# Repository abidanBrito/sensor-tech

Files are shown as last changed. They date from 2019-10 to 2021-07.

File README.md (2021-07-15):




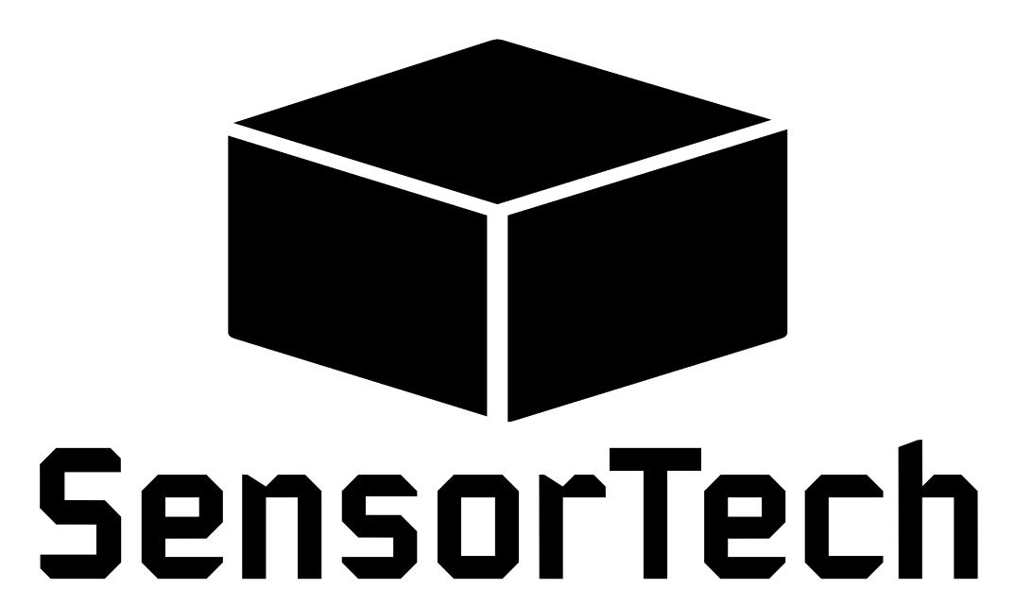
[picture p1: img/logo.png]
Project_Logo


Electronic prototype to **monitor several environmental magnitudes** through self-implemented sensors. Field data collection at your fingertips!

## TABLE OF CONTENTS
1.  [Motivation](#motivation)
2.  [Technologies and Frameworks](#technologies-and-frameworks)
3.  [System Design](#system-design)
4.  [Functionalities and Features](#functionalities-and-features)
5.  [Documentation](#documentation)
6.  [Acknowledgements](#acknowledgements)

## MOTIVATION
This project is a team effort for our first semester class CDIO. It aims to **optimize all agricultural activity**, providing meaningful realtime data.

## TECHNOLOGIES AND FRAMEWORKS
### Electronic Devices and Components
*   Sparkfun **ESP8266 Thing Dev** Board.
*   Adafruit **ADS1115** 16-bit ADC.
*   DFROBOT **SEN0193** Soil Moisture Sensor.
*   Lantronix **A2235-H** GPS Receiver.
*   InvenSense **MPU-9250** Accelerometer.
*   Adafruit **BMP280** Barometric Pressure & Altitude Sensor.
*   **HC-SR04** Ultrasonic Distance Sensor. 
*   Operational amplifier.
*   Photodiode.
*   AND logic gate.
*   NTC thermistor.
*   Resistors.

### REST APIs
*   ThingSpeak - IoT Analytics and integration with MATLAB.
*   Dweet - Simple messaging and alerts. 

### Software Development 
*   Arduino IDE. 
*   Third-party text editors.

## SYSTEM DESIGN
### Sofware Architecture
Check the [documentation](Technical_Documentation.pdf) (spanish) for a detailed breakdown of both the overall design and the dependencies it relies on.

### Hardware Architecture
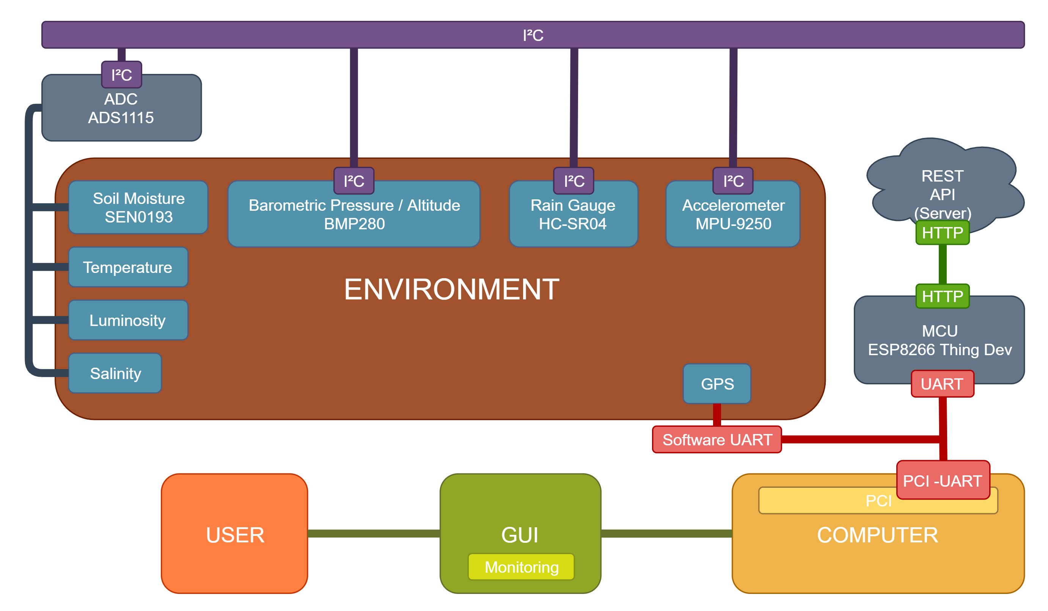
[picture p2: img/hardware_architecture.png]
Hardware Architecture Diagram

Refer to the [documentation](Technical_Documentation.pdf) (spanish) for further details and schematics.

## FUNCTIONALITIES AND FEATURES 
*   \[x] Salinity sensor (electrical conductivity).
*   \[x] Soil Moisture sensor.
*   \[x] Temperature sensor.
*   \[x] Luminosity sensor.
*   \[x] Barometric pressure and altitute sensor.
*   \[x] Anti-theft system (Wake on Motion).
*   \[x] Hibernation mode (Deep Sleep).
*   \[x] Rain Gauge (experimental).
*   \[x] GPS receiver.
*   \[x] REST server.
*   \[x] PCB Design.

## DOCUMENTATION
Please, refer to the [technical documentation](Technical_Documentation.pdf) (spanish) if you have any doubts about the system. It can be found in the form of a PDF file, which goes over everything you need to get you up and running, from schematics and pins to dependencies and sensor calibration.

## ACKNOWLEDGEMENTS
I would like to express my sincere gratitude to my teacher **Mª Asunción Pérez Pascual** for her invaluable support, feedback and encouragement throughout the development of this project, and to **Universitat Politècnica de València** for providing us with both the knowledge and the tools needed to complete it.

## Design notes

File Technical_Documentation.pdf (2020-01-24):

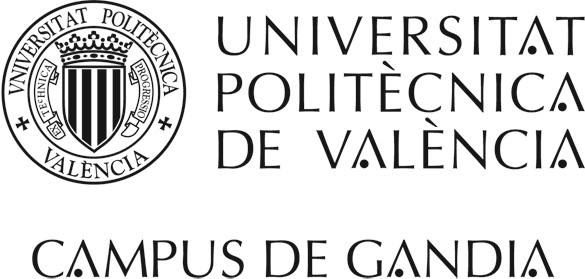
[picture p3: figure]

1

## Proyecto GTI_1A (GTI_1A_19_TEAM_02)

## Sonda agrícola e-Horta

## Documento Técnico de Diseño

Volumen 1

Documento Técnico de Diseño | Pág.2
GTI 1A 19 TEAM 02
Vol. 1
ÍNDICE
PROPÓSITO | 6
ALCANCE | 6
DEFINICIONES, ACRÓNIMOS Y ABREVIATURAS | 6
ESTRUCTURA DEL DOCUMENTO | 7
CARACTERÍSTICAS DEL SISTEMA | 7
Tabla 1. Funcionalidades | 8
ARQUITECTURA HARDWARE DEL SISTEMA | 8
Diagrama de bloques | 8
Ilustración 1. Diagrama de bloques | 8
Esquemático del circuito | 8
Ilustración 2. Esquemático del circuito | 8
PCB implementado | 9
Ilustración 3. Diseño de la PCB | 9
MEDIDA HUMEDAD | 9
Descripción | 9
Ilustración 4. Esquemático del sensor de humedad | 10
Calibración | 10
Testeo | 10
Tabla 2. Valores de humedad | 11
MEDIDA SALINIDAD | 11
Descripción | 11
Ilustración 5. Esquemático del sensor de salinidad | 11
Calibración | 11
Gráfica 1. Valores del sensor de salinidad | 11
Testeo | 11
Gráfica 2. Valores de Salinidad | 12
MEDIDA TEMPERATURA | 12
Descripción | 12
Ilustración 6. Esquemático del sensor de temperatura | 13
Calibración | 13
Testeo | 13
Gráfica 3. Valores del sensor de temperatura | 13

Vol. 1

PRESIÓN BAROMÉTRICA Y ALTITUD | 13
Descripción | 13
Ilustración 7. Esquemático del sensor de presión barométrica | 14
Calibración | 14
Testeo | 14
LUZ AMBIENTE | 14
Descripción | 14
Ilustración 8. Esquemático del sensor de luminosidad | 15
Calibración | 15
Tabla 3. Valores del sensor de luminosidad | 15
Testeo | 15
PLUVIÓMETRO | 15
Descripción | 15
Ilustración 9. Esquemático del pluviómetro | 15
Calibración | 15
Testeo | 15
LOCALIZACIÓN | 16
Descripción | 16
Ilustración 10. Esquemático del GPS | 16
Calibración | 16
Testeo | 16
RED DE NODOS | 16
Ilustración 11. Red de nodos | 17
SOFTWARE | 17
CLASES | 17
Ilustración 12. Diagrama de la clase del sensor BMP280 | 17
Ilustración 13. Diagrama de la clase del sensor SEN0193 | 18
Ilustración 14. Diagrama de la clase del sensor de luminosidad | 18
Ilustración 15. Diagrama de la clase del sensor de temperatura | 18
Ilustración 16. Diagrama de la clase del pluviómetro | 19
Ilustración 17. Diagrama de la clase del sensor de salinidad | 19
LIBRERÍAS | 19
PROGRAMA | 19
Ilustración 18. Diagrama de la configuración del programa | 20

Vol. 1
Figuras
Ilustración 1. Diagrama de bloques | 8
Ilustración 2. Esquemático del circuito | 8
Ilustración 3. Diseño de la PCB | 9
Ilustración 4. Esquemático del sensor de humedad | 9
Ilustración 5. Esquemático del sensor de salinidad | 10
Ilustración 6. Esquemático del sensor de temperatura | 11
Ilustración 7. Esquemático del sensor de presión barométrica | 12
Ilustración 8. Esquemático del sensor de luminosidad | 13
Ilustración 9. Esquemático del pluviómetro | 14
Ilustración 10. Esquemático del GPS | 15
Ilustración 11. Red de nodos | 15
Ilustración 12. Diagrama de la clase del sensor BMP280 | 16
Ilustración 13. Diagrama de la clase del sensor SEN0193 | 16
Ilustración 14. Diagrama de la clase del sensor de luminosidad | 17
Ilustración 15. Diagrama de la clase del sensor de temperatura | 17
Ilustración 16. Diagrama de la clase del pluviómetro | 17
Ilustración 17 Diagrama de la clase del sensor de salinidad | 18
Ilustración 18. Diagrama del programa completo | 18

Vol. 1
TABLAS Y GRÁFICAS
Tabla 1. Funcionalidades | 7
Tabla 2. Valores de humedad | 10
Gráfica 1. Valores del sensor de salinidad | 11
Tabla 3. Valores del sensor de luminosidad | 13
Gráfica 3. Valores del sensor de temperatura | 13

Vol. 1

### 1 INTRODUCCIÓN

E-Horta es una sonda agrícola capaz de realizar lecturas de diversas magnitudes físicas. Recopila información de campo sensible, a fin de monitorizar y optimizar la actividad agrícola.
Este prototipo electrónico recoge datos de la humedad de la tierra, la salinidad y temperatura del agua de riego, la temperatura ambiente, la presión barométrica, la altitud del terreno, la intensidad lumínica, el volumen de precipitaciones y la geolocalización del dispositivo. Además, incorpora un pequeño sistema antirrobo y otro de autoabastecimiento (célula fotovoltaica y batería).
Para minimizar el consumo energético, la sonda realiza mediciones cada cierto tiempo (configurable). Inmediatamente entra en modo de hibernación o stand-by, hasta la siguiente captura de datos o la interrupción física (vibraciones).
Para implementar las susodichas funcionalidades, se ha optado por utilizar el microcontrolador SparkFun ESP8266 Thing Dev, el convertidor analógico-digital Adafruit ADS1115 16-bit, sensores varios (tanto analógicos como digitales) y múltiples componentes electrónicos. Este microcontrolador tiene la ventaja de utilizar la plataforma de desarrollo Arduino, y está programado en lenguaje C++.

### 1.1 PROPÓSITO

En este documento se especifican las características técnicas del producto, así como su funcionamiento. Además, proporciona información sobre los sensores utilizados.
Éste es un documento técnico dirigido a un público con conocimiento tecnológico mínimo, relativo al campo de la electrónica y la programación.
Su redacción pretende exponer de manera rigurosa y objetiva las capacidades, propiedades y limitaciones de e-Horta. Con ello, se espera concretar las amplias posibilidades del producto.

### 1.2 ALCANCE

Este prototipo tiene como finalidad que el cliente sepa en todo momento la situación de su campo, sin necesidad de ir a éste todos los días, y poder saber cuándo tiene que regar más, o cuándo el agua tiene demasiada sal y puede estropear los cultivos.
El sistema es capaz de mostrar los niveles de humedad, salinidad, temperatura en agua, temperatura ambiente, presión barométrica, altitud, luminosidad y precipitaciones. También está equipado con un sistema de posicionamiento global. El dispositivo se encuentra aislado en una caja estanca; se puede estropear si alguno de sus componentes internos entra en contacto con el agua, provocando un cortocircuito.

Vol. 1

### 1.3 DEFINICIONES, ACRÓNIMOS Y ABREVIATURAS

ADC: Convertidor analógico-digital (Analog-to-Digital Converter).
GPS: sistema de posicionamiento global (Global Positioning System).
PCB: placa de circuito impreso (Printed Circuit Board); superficie constituida por buses de un material conductor, laminadas sobre una base no conductora.
API: interfaz de programación de aplicaciones (Application Programming Interface). REST: transferencia de estado representacional (Representational State Transfer); estilo de arquitectura software para sistemas hipermedia distribuidos.
CEI: Comisión Electrotécnica Internacional.
RAEE: Residuos de Aparatos Eléctricos y Electrónicos.
IDE: entorno de desarrollo integrado (Integrated Development Environment). TCP: Transmission Control Protocol.
IP: Internet Protocol address.
HTTP: Hypertext Transfer Protocol.
UART: Universal Asynchronous Receiver-Transmitter. I2C: Inter-Integrated Circuit.
WOM: Wake on Motion.
NMEA: National Marine Electronics Association.
deepSleep: función del microcontrolador que le permite activar el modo Stand-by. BMP280: sensor digital de presión barométrica absoluta, altitud y temperatura ambiente.
MPU9250: acelerómetro utilizado para el sistema antirrobo.
A2235-H: recibidor de GPS utilizado.
SEN0193: sensor de humedad del suelo utilizado.
Buck-boost: convertidor DC-DC con un voltaje de salida mayor o menor que el voltaje de entrada.
Célula fotovoltaica / fotocélula: dispositivo electrónico que permite transformar la energía lumínica en energía eléctrica mediante el efecto fotoeléctrico, generando energía solar fotovoltaica.

Vol. 1

### 1.4 ESTRUCTURA DEL DOCUMENTO

El documento sigue la siguiente estructuración lógica de los contenidos:
1) Introducción concisa, descripción detallada del proyecto y documentos referenciados.
2) Visión general del sistema.
3) Funcionalidades, calibraciones y testeos del prototipo.
4) Mapa de red de nodos.
5) Software implementado y dependencias (librerías).
6) Conclusiones del trabajo realizado y posibles líneas de mejora.
7) Referencias del documento.

### 2 SISTEMA

El funcionamiento del sistema se basa en la transferencia de datos extraídos / capturados por los sensores al microcontrolador. Posteriormente, son enviados a un servidor web (API REST), que los muestra al usuario final en forma de gráficos. Finalmente, el microcontrolador entra en modo hibernación (deepSleep), “se duerme”, para ahorrar energía. No obstante, si alguien intentase robarlo, éste se despertaría ipso facto y notificaría la incidencia.

### 2.1 CARACTERÍSTICAS DEL SISTEMA

El sistema se alimenta a través de una pequeña célula fotoeléctrica, acoplada a un convertidor buck-boost y una batería de litio. El convertidor buck-boost se utiliza para garantizar un nivel de voltaje de salida estable.
Para maximizar la eficiencia energética utilizamos el modo deepSleep y una PCB. Esta última además de mejorar el diseño, mantenimiento y apariencia, también evita cambios bruscos de impedancia y reflexiones en altas frecuencias.
Como medida de protección, se ha optado por aislar toda la circuitería en una caja estanca, cuyo grado de protección es IP55, de acuerdo con la regulación de la norma CEI 60529. Es decir, protección contra polvo y frente a chorros de agua. Como medida de seguridad, se ha implementado un rudimentario sistema antirrobo, utilizando el acelerómetro para detectar vibraciones o movimientos, compartiendo el bus de interrupción con la interrupción del modo deepSleep.
La directiva 2011/65/UE es aplicable. El producto también cumple la normativa europea de concentración máxima de sustancias peligrosas. El reciclaje de aparatos eléctricos y electrónicos es una cuestión sensible. Éstos están formados por diferentes materias peligrosas. La negligencia de su correcto tratamiento o reciclaje puede suponer contaminación ambiental. Siguiendo el Real Decreto 110/2015, se insta a extraer los componentes internos de la caja y llevarlos al punto limpio más cercano; depositando la caja y los residuos electrónicos por separado y en sus respectivas localizaciones. El reciclaje de los RAEE depende del papel activo de

Vol. 1

cada uno de nosotros. Debemos concienciarnos y entender la responsabilidad y deuda ecológica que ello conlleva.
Los siguientes sensores cumplen la normativa RoHS: MPU-9250, BMP280, A2235-H.
Parámetro | Mín. | Máx. | Unidades
Humedad | Seco | Sumergido | %
Salinidad | Agua destilada | Cortocircuito | %
Temperatura | 0 | 40 | ºC
Presión | 300 | 1100 | hPa
Luz | Oscuridad (0) | Soleado (3.7) | mV
Pluviómetro | 0 | 0.45 | l
Altitud | -150 | 9140 | m
Tabla 1. Funcionalidades con sus rangos de medida

### 2.2 ARQUITECTURA HARDWARE DEL SISTEMA

### 2.2.1 Diagrama de bloques

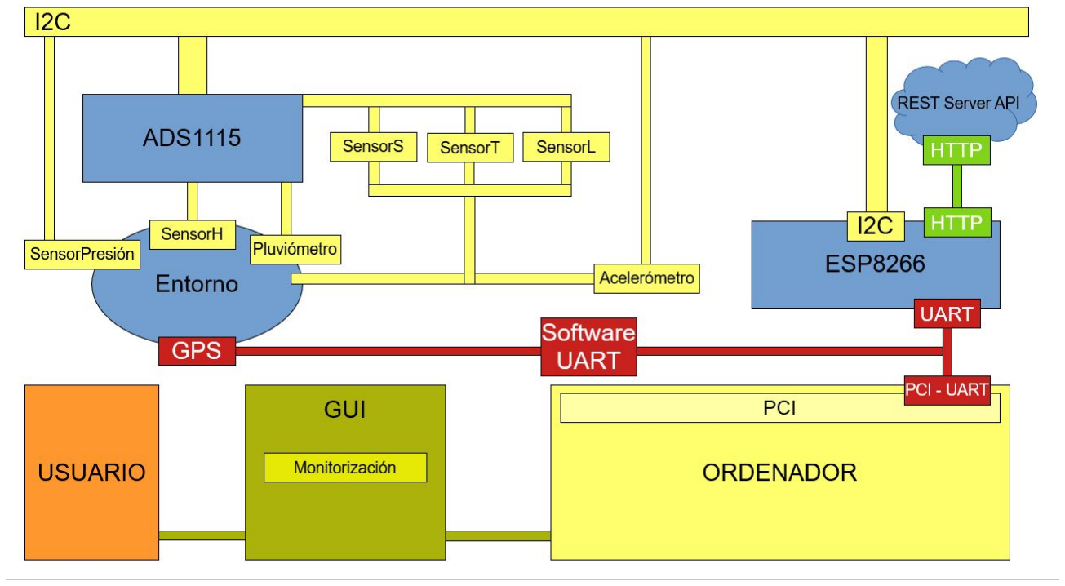
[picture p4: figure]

Ilustración 1. Diagrama de bloques

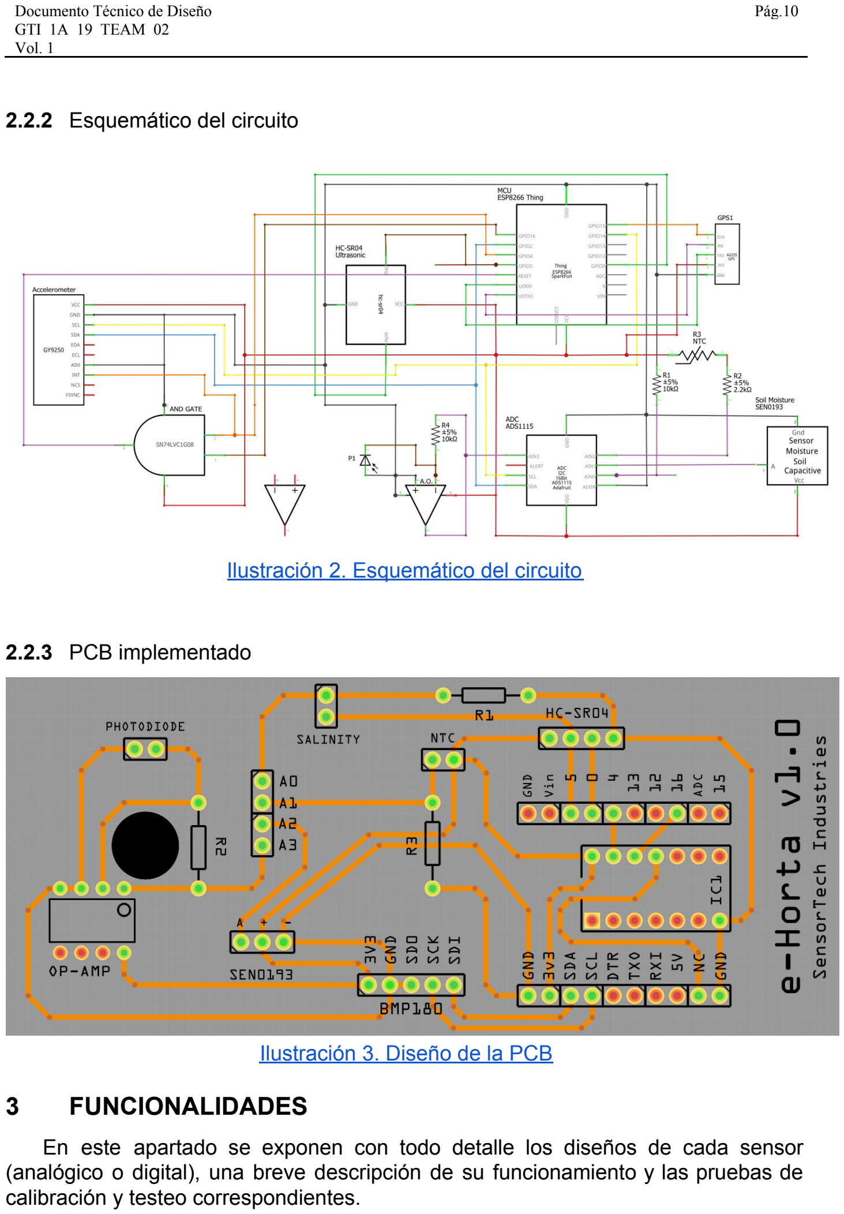
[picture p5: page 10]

Vol. 1

### 2.2.2 Esquemático del circuito

Ilustración 2. Esquemático del circuito

### 2.2.3 PCB implementado

Ilustración 3. Diseño de la PCB

### 3 FUNCIONALIDADES

En este apartado se exponen con todo detalle los diseños de cada sensor (analógico o digital), una breve descripción de su funcionamiento y las pruebas de calibración y testeo correspondientes.

Vol. 1

### 3.1 MEDIDA HUMEDAD

### 3.1.1 Descripción

Este sensor realiza 5 mediciones consecutivas (a milisegundos de diferencia) del nivel de humedad del subsuelo. Se devuelve un promedio de éstas para minimizar la incertidumbre en la medida. El datasheet del sensor utilizado puede encontrarse aquí. (https://poliformat.upv.es/access/content/group/GRA_13924_2019/Datasheets/Capacitive%20Soil%20Moisture%20Sensor%20SKU_SEN0193%20-%20DFRobot%20Electronic%20Prod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) A continuación adjuntamos el esquemático del sensor:

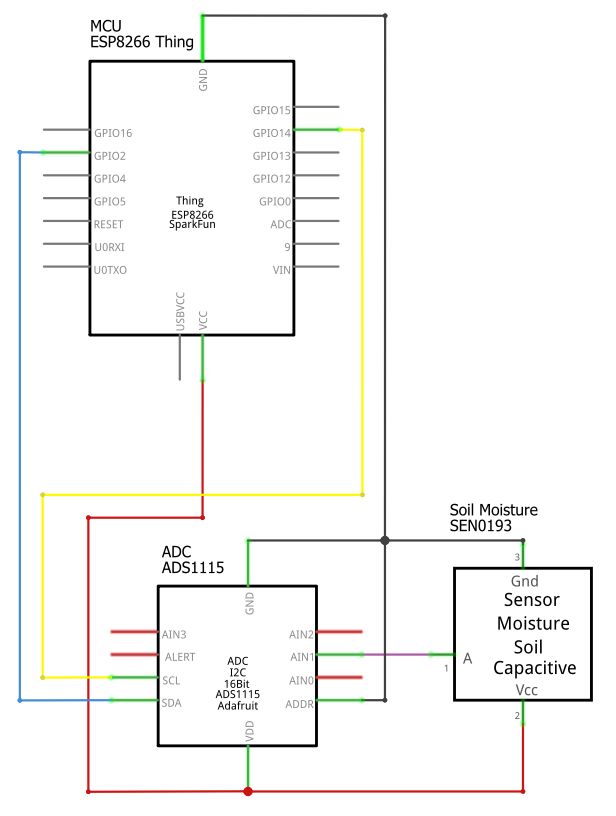
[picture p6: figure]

Ilustración 4. Esquemático del sensor de humedad

Vol. 1

### 3.1.2 Calibración

Para calibrar este sensor se toma primero una medida en seco, tomando ese valor como nivel de referencia o límite de calibración inferior. De esa manera, la humedad ambiental no influirá en la medida (al menos no en gran medida, ya que la humedad del aire no es constante). Análogamente, se toma otra medida sumergido en agua, estableciendo el máximo de humedad.
Los valores recibidos aquí son de 400 mV en seco y 1.5 V metido en agua como media de 10 medidas.

### 3.1.3 Testeo

Para probar este sensor tenemos que tomar una medida en agua, y que los valores de humedad se aproximen al 100%, y otra en seco, y que los valores se aproximen al 0%.

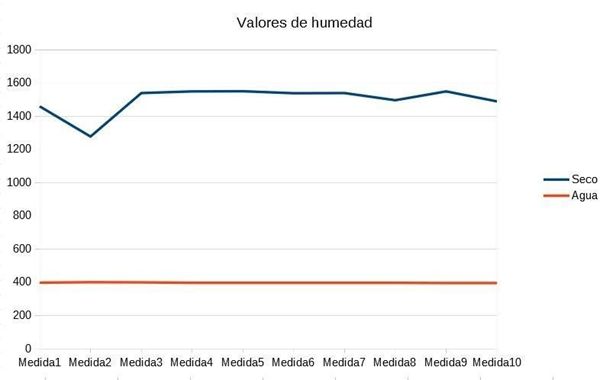
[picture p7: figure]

Tabla 2. Valores de humedad

Vol. 1

### 3.2 MEDIDA SALINIDAD

### 3.2.1 Descripción

El sensor de salinidad se basa en la conductividad eléctrica de las soluciones salinas debido al efecto de la atracción interiónica. Como el agua será mejor conductor eléctrico en proporción directa a la cantidad de sal disuelta que contenga, medimos la salinidad según la conductividad del ésta. Esto lo haremos usando dos cables a modo de terminales, siguiendo el esquemático aquí expuesto y mediremos el voltaje, teniendo en cuenta que el agua ejerce una resistencia lineal. A continuación adjuntamos el esquemático del sensor:

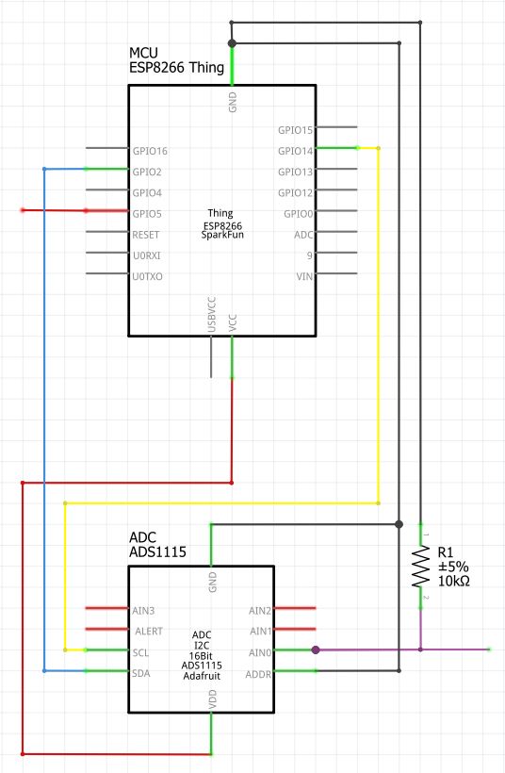
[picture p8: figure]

Ilustración 5. Esquemático del sensor de salinidad

Vol. 1

### 3.2.2 Calibración

Para calibrar este sensor hemos puesto como mínimo una tensión de 0 voltios (circuito abierto, impedancia máxima) y, como máximo, la tensión en cortocircuito (máxima continuidad, mínima impedancia).

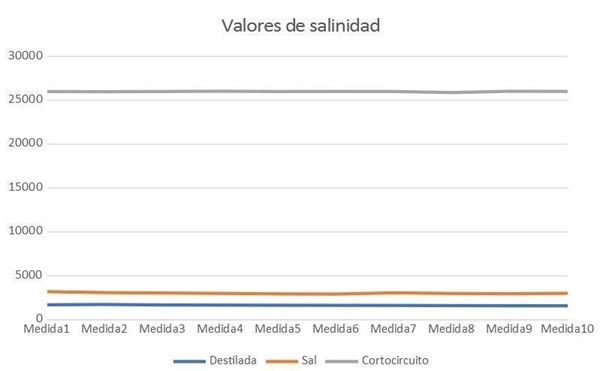
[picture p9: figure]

Gráfica 1. Valores del sensor de salinidad

### 3.2.3 Testeo

Para los testeos se utilizaron un vaso con agua destilada y otro con 100mL de agua y 10 gramos de sal, es decir, con un 10% de salinidad. Al realizar las pruebas comprobamos que los datos recibidos del agua destilada no son 0V, ya que en la práctica sí conduce la electricidad.

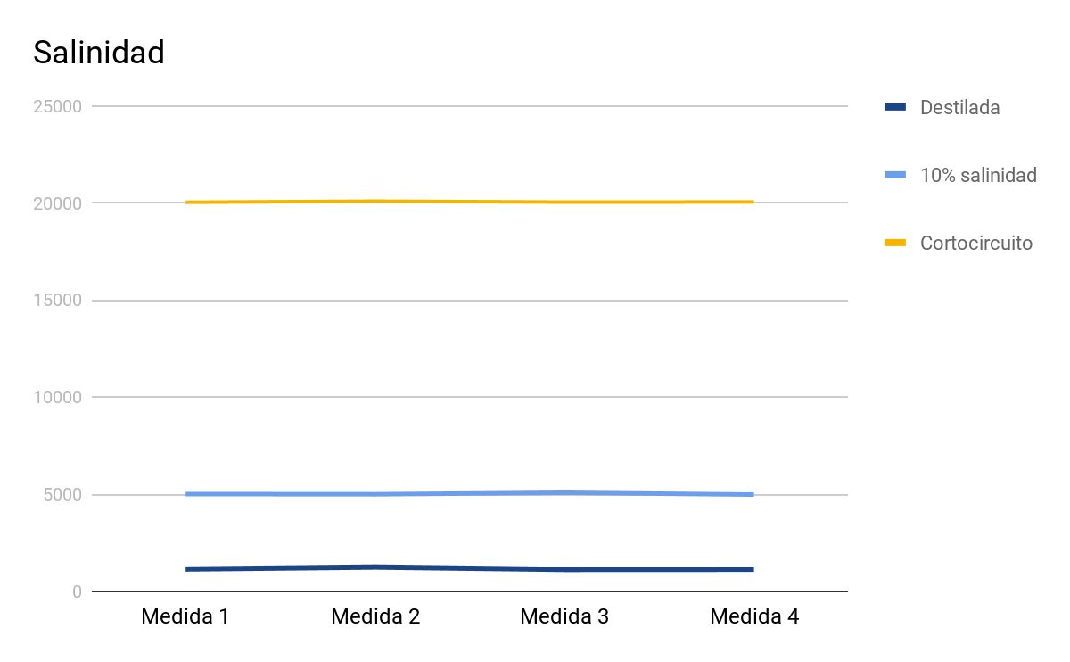
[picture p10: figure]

Gráfica 2. Valores de Salinidad

Vol. 1

Se aprecia que los datos varían ligeramente entre medidas, pero dentro de un margen de error razonable.

### 3.3 MEDIDA TEMPERATURA

### 3.3.1 Descripción

Este sensor, formado por una NTC (resistencia con temperatura variable) cuya referencia es K1642K2, cambia sus valores dependiendo de la temperatura y, aplicando la fórmula T′ = ΔT + , podemos conseguir la temperatura que hay en m

V o − b
el agua. A continuación adjuntamos el esquemático del sensor:

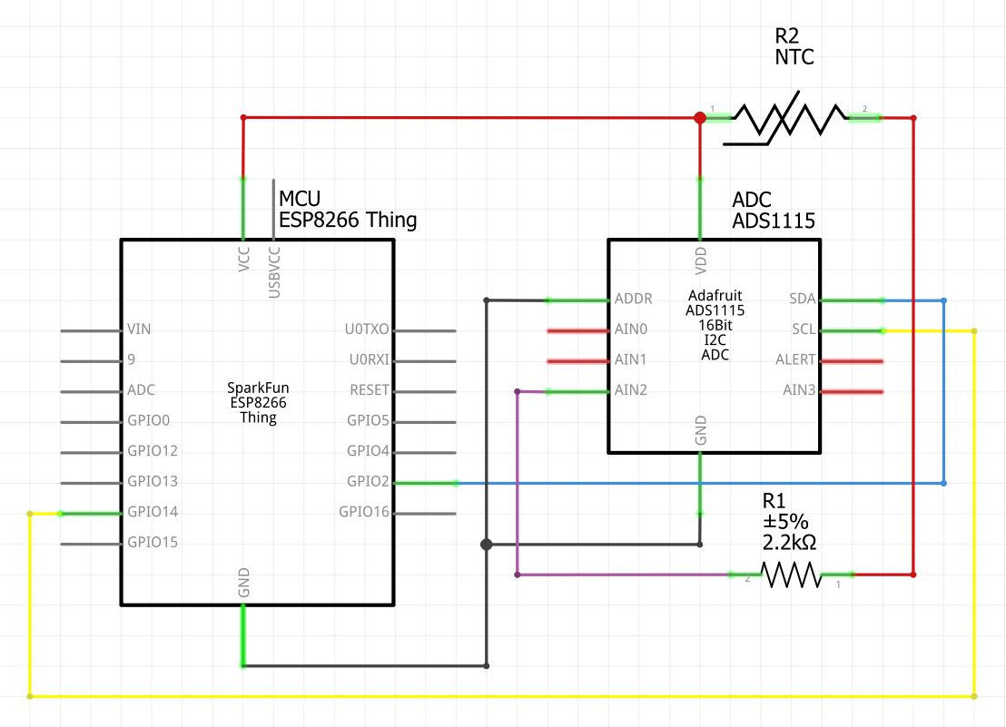
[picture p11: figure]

Ilustración 6. Esquemático del sensor de temperatura

### 3.3.2 Calibración

La calibración del termistor se lleva a cabo de forma teórica, usando la fórmula anteriormente expuesta, en cuyo caso sus valores constantes serían b = 0.786 , m = 0.0348 . Posteriormente, se le suma la desviación de los valores para calibrar el error del sensor. Esto es ΔT = − 0.24 .

### 3.3.3 Testeo

Para probar este sensor debemos meter un termómetro y el sensor en un vaso de agua, y añadirle agua caliente y ver como la temperatura del termómetro y el

Vol. 1

termistor aumenta. Seguidamente le añadimos agua fría o hielo y observar como la temperatura del termómetro y el termistor disminuye, siendo ambas muy parecidas. Vemos en la documentación (https://poliformat.upv.es/access/content/group/GRA_13924_2019/Datasheets/NTC_K164.pdf) del sensor que su comportamiento es lineal dentro del rango definido entre 0 ºC y 40 ºC.

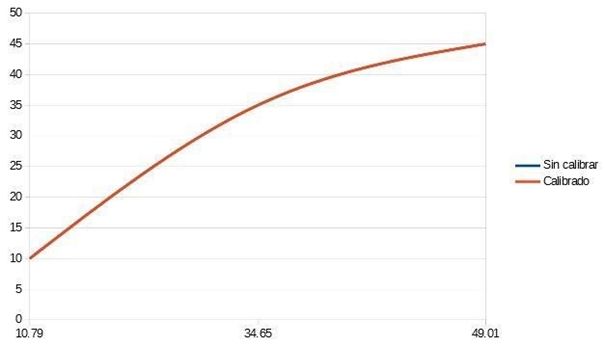
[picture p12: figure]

Gráfica 3. Valores del sensor de temperatura

### 3.4 PRESIÓN BAROMÉTRICA Y ALTITUD

### 3.4.1 Descripción

El sensor BMP280 de Bosch (se adjunta su ficha técnica (http://descargas.cetronic.es/BOSCHBMP280.pdf) en inglés) muestra medidas de presión barométrica, altitud y temperatura ambiente. A continuación adjuntamos el esquemático del sensor:

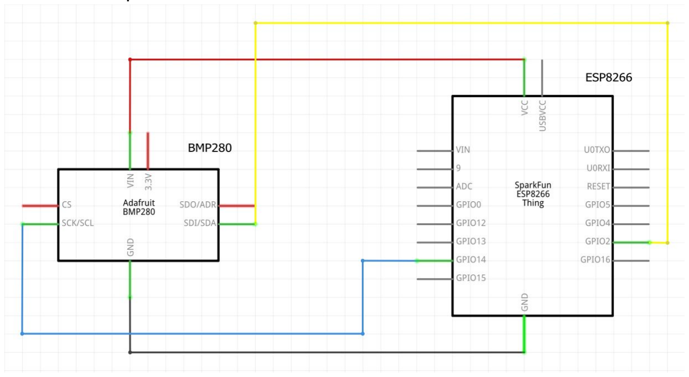
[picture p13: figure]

Ilustración 7. Esquemático del sensor de presión barométrica

### 3.4.2 Calibración

Vol. 1

Este es un sensor digital que no requiere calibración. No obstante, se debería de utilizar su propia medida de la altitud para determinar un valor aproximado de presión barométrica. Las medidas del sensor son aproximadas, pero fiables, siempre se encuentre dentro del siguiente rango (-150, 9140), expresado en metros.

### 3.4.3 Testeo

Para probar este sensor debemos comparar el valor que envía el sensor con los valores de presión y altitud reales, y observar que al aumentar la temperatura, la presión también aumenta, debido a la excitación de las moléculas.

### 3.5 LUZ AMBIENTE

### 3.5.1 Descripción

Este sensor, formado por el fotodiodo VTB8441 (se adjunta su ficha técnica), (http://www.datasheetcatalog.com/info_redirect/datasheet/perkinelmer/VTB8441.pdf.shtml) capta la luz y transmite el estado de iluminación ambiente. Dicho sensor puede determinar cuatro estados: tapado / oscuro, nublado / en penumbra, despejado y soleado / luz intensa. A continuación adjuntamos el esquemático del sensor:

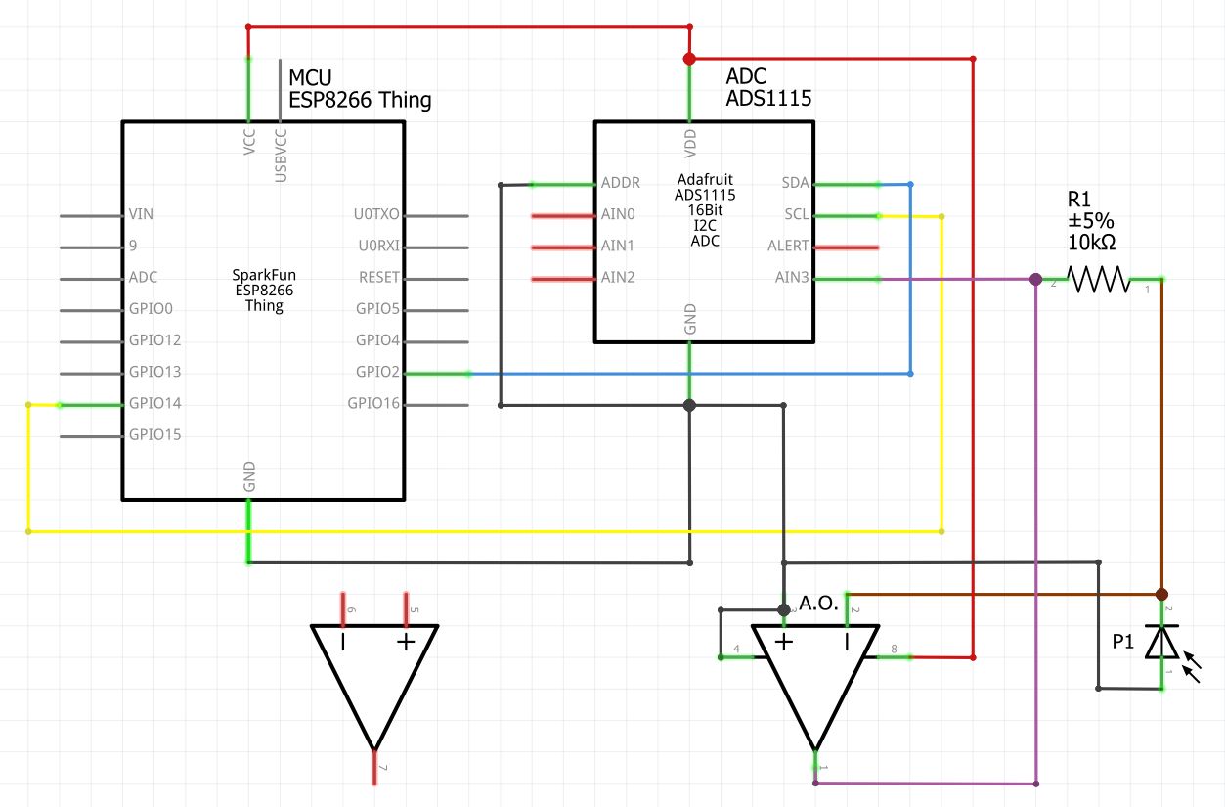
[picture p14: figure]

Ilustración 8. Esquemático del sensor de luminosidad

### 3.5.2 Calibración

La calibración de este sensor se realiza midiendo los valores recibidos en diferentes estados de luz, de donde se deducen los rangos de luminosidad que va a tener el sensor.

Vol. 1

Condición | Tapado / oscuro | Nublado / en penumbra | Despejado | Soleado / luz intensa
V output | [0, 7] mV | (7, 35] mV | (35, 350) mV | [350 - 3700] mV

Tabla 3. Valores del sensor de luminosidad

### 3.5.3 Testeo

Para probar este sensor se debe tapar el fotodiodo y comprobar que el programa determina el estado “tapado / oscuro”. Análogamente, si se le hace sombra debería determinar “nublado / en penumbra”. Si tiene luz ambiental y no está en sombra; “despejado”. Y, si se enfoca una linterna con los suficientes lúmenes; “soleado / luz intensa”.

### 3.6 PLUVIÓMETRO

### 3.6.1 Descripción

Este sensor de ultrasonidos devuelve el volumen en litros del vaso. A continuación adjuntamos el esquemático del sensor:

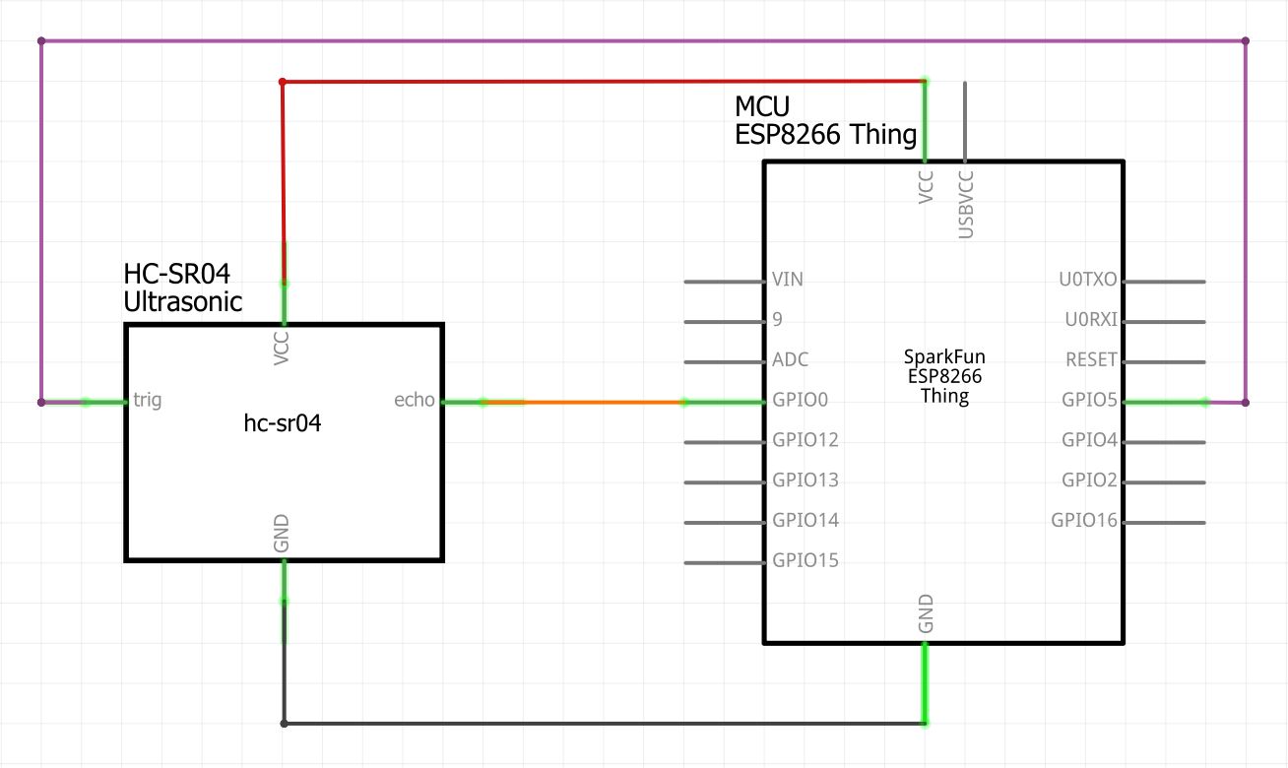
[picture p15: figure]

Ilustración 9. Esquemático del pluviómetro

### 3.6.2 Calibración

Para calibrar este sensor se debe medir el diámetro y la altura del vaso y aplicar la fórmula V = h * πr , siendo h la altura y r el radio del vaso. Para una taza este ² volumen es de aproximadamente 477.52 cm .

3

Vol. 1

### 3.6.3 Testeo

Para probar este sensor debemos apuntarlo hacia el vaso vacío y observar que devuelve 0, y al empezar a llenarlo devuelve valores mayores, sin pasarse del volumen máximo.

### 3.7 LOCALIZACIÓN

### 3.7.1 Descripción

Este sensor se ha utilizado para determinar la geolocalización del dispositivo por triangulación. Muestra la fecha, la hora, la latitud, la longitud, la altitud, el rumbo y la velocidad en formato de mensaje NMEA. A continuación adjuntamos el esquemático del sensor:

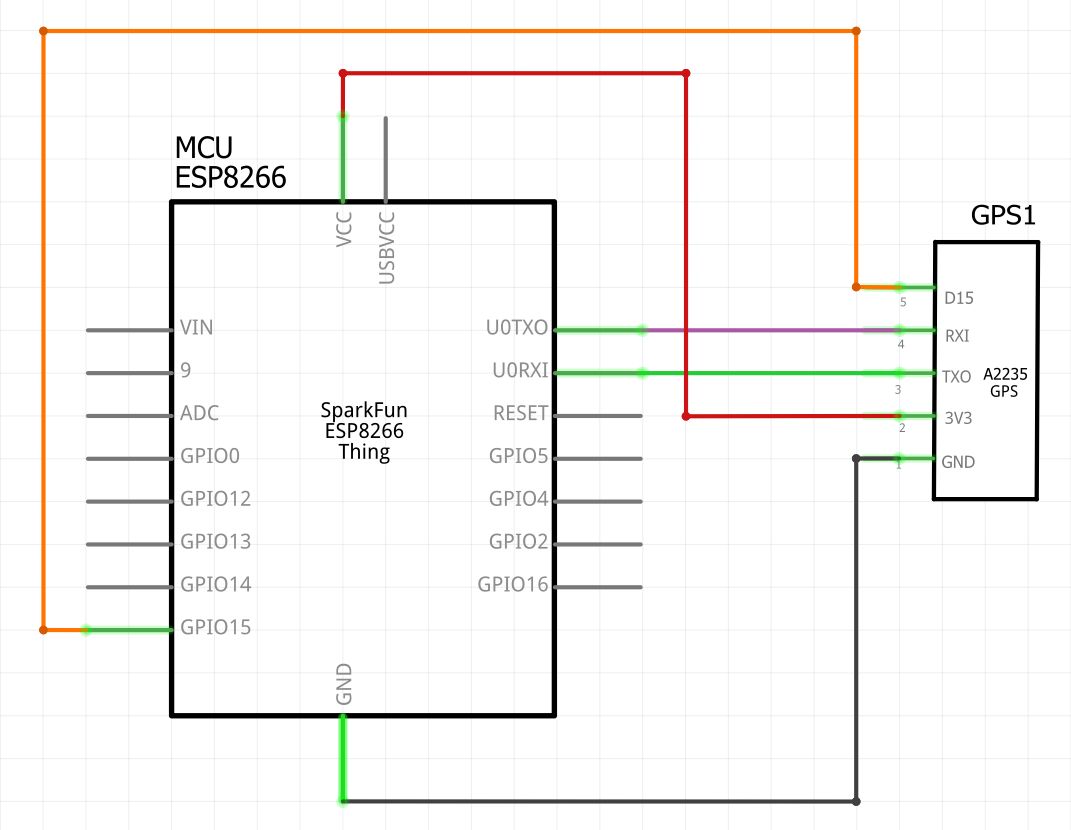
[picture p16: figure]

Ilustración 10. Esquemático del GPS

### 3.7.2 Calibración

Este sensor no precisa de calibración.

### 3.7.3 Testeo

Para probar este sensor debemos observar los datos que nos da y compararlos con los de un GPS comercial, como puede ser el de un móvil. Google ofrece el servicio de geolocalización Google Maps el cual usaremos para esta finalidad.

Vol. 1

### 4 RED DE NODOS

Se puede desglosar el camino de los datos de manera esquemática en los siguientes 5 niveles: comunicación hardware (nivel 0), acceso a la red (nivel 1), internet (nivel 2), transporte (nivel 3), aplicación (nivel 4).
En primer lugar nuestro microcontrolador se comunica con los sensores mediante el protocolo I2C, y con el ordenador mediante el protocolo UART (con la finalidad de enviar y mostrar los datos recogidos en el monitor serial del Arduino IDE). Éstos, son enviados mediante conexión inalámbrica (Wi-Fi) al servidor, utilizando el protocolo IP. Ya que la conexión a Internet es la función que más consume, y no es necesario enviar datos en grandes cantidades, se utiliza el protocolo TCP. Finalmente estos datos acaban en el servidor web mediante el protocolo HTTP. Nótese que, en la práctica no sería necesario tener el prototipo conectado a ningún otro dispositivo, pues es autosuficiente y los datos serían enviados directamente al servidor. A continuación, adjuntamos la siguiente ilustración a modo de ayuda visual. No obstante, en el nivel 0 debería estar representado el ya mencionado protocolo I2C.

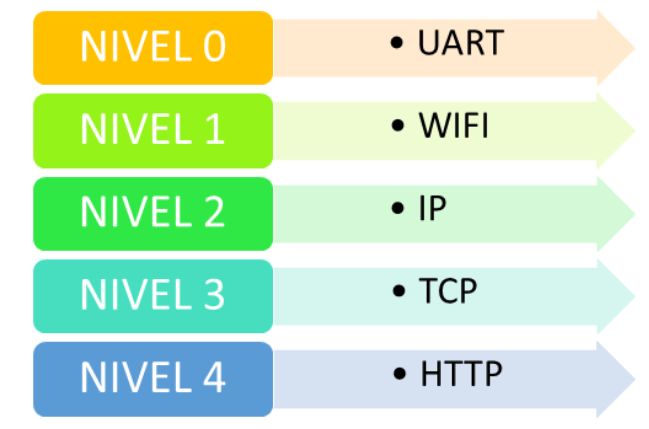
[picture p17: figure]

Ilustración 11. Red de nodos

### 5 SOFTWARE

Teniendo en cuenta que la parte software del proyecto se ha desarrollado íntegramente en Arduino, todos los programas han sido implementados en el lenguaje de programación C++. La base de código sigue el paradigma de orientación a objetos. De esta manera, existe una clase por tipo de sensor. Esto quiere decir que de ser necesario se podrían implementar varios sensores de un mismo tipo creando una nueva instancia de esa clase, definiendo su configuración en la inicialización del objeto creado. Otras funcionalidades como el recibidor GPS o

Vol. 1

las interrupciones constan de librerías independientes. En general, se ha apuntando por un diseño escalable, modular y coherente, pero sin complejidad añadida. Encuéntrese el código en su totalidad en el repositorio del proyecto. (https://github.com/abidanBrito/CDIO-SensorTech)

5.1 CLASES

Se adjuntan a continuación los diseños de las clases implementados, en forma de diagramas UML. Pero, con notación matemática. Los símbolos corresponden a números reales ( R ), enteros ( Z ) y naturales ( N ).

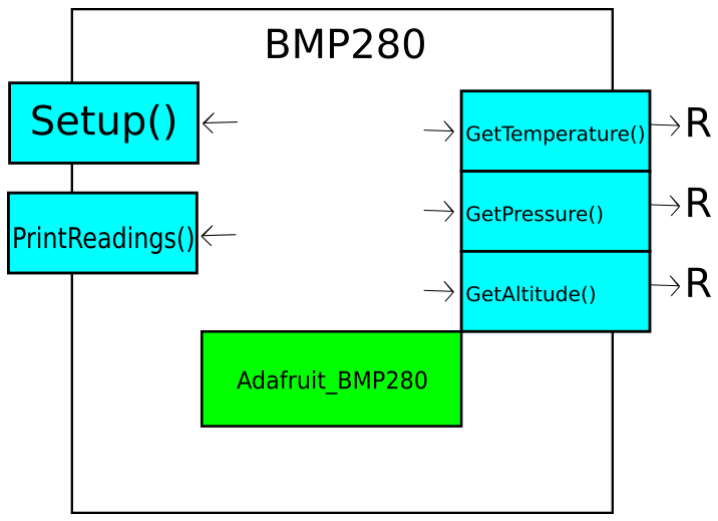
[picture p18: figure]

Ilustración 12. Diagrama UML del sensor BMP280.

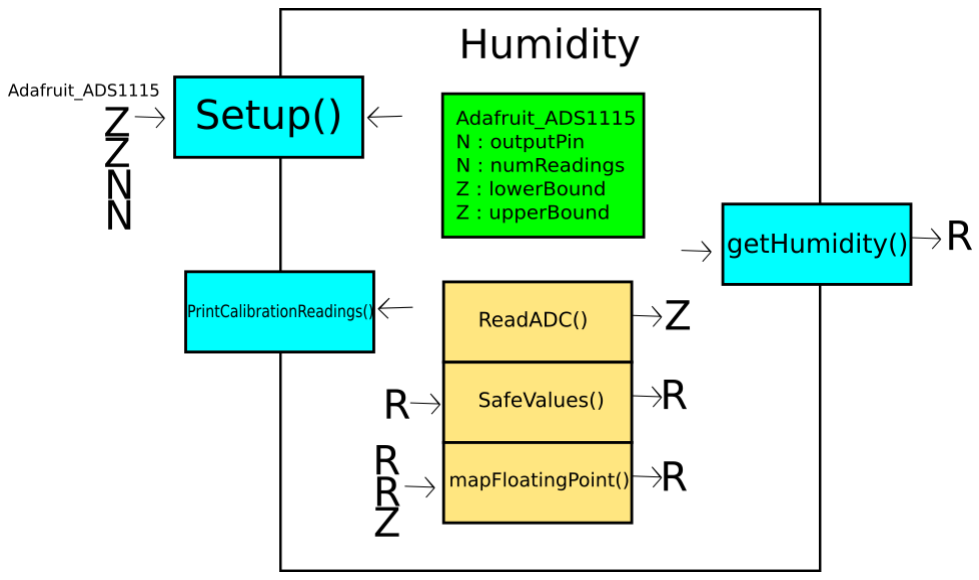
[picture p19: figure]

Ilustración 13. Diagrama UML del sensor SEN0193.

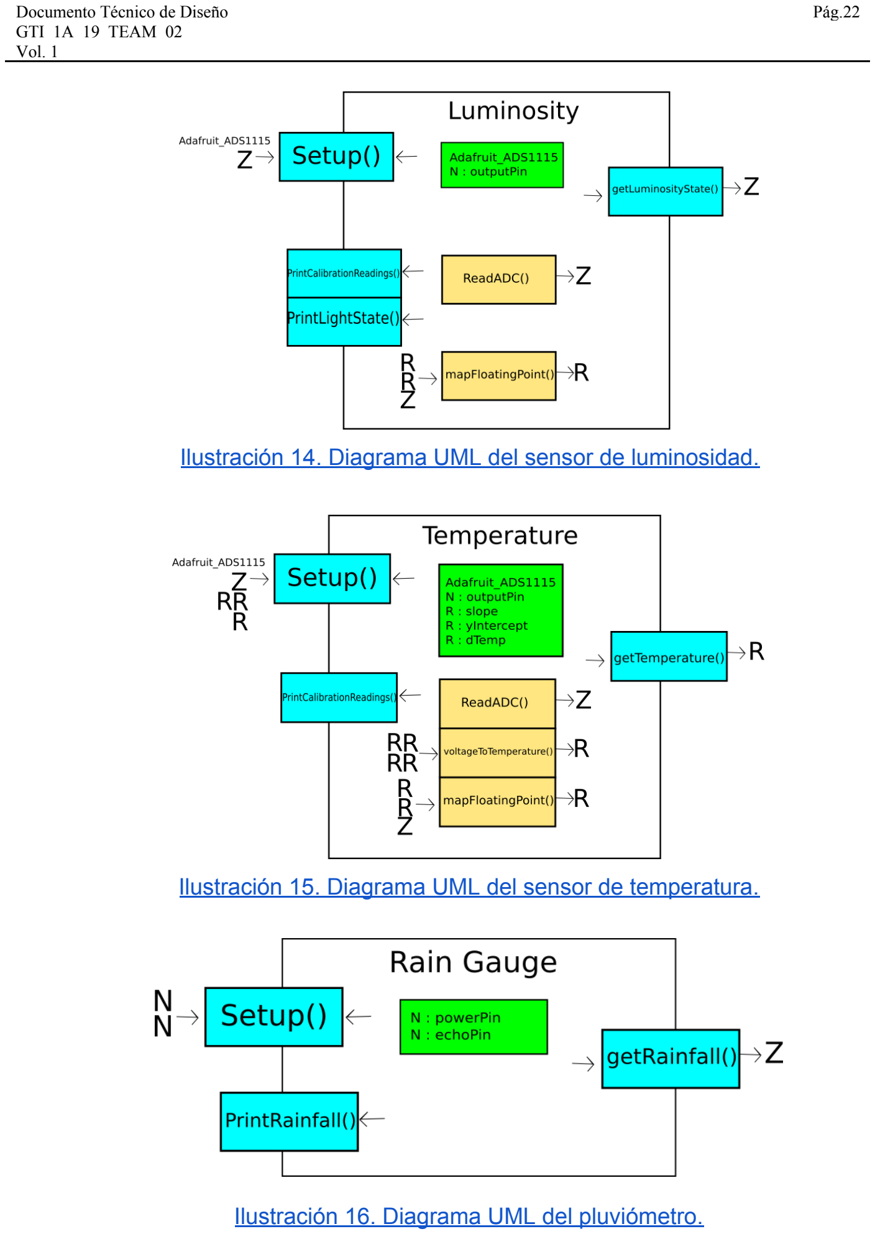
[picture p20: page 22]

Vol. 1

Ilustración 14. Diagrama UML del sensor de luminosidad.

Ilustración 15. Diagrama UML del sensor de temperatura.

Ilustración 16. Diagrama UML del pluviómetro.

Vol. 1

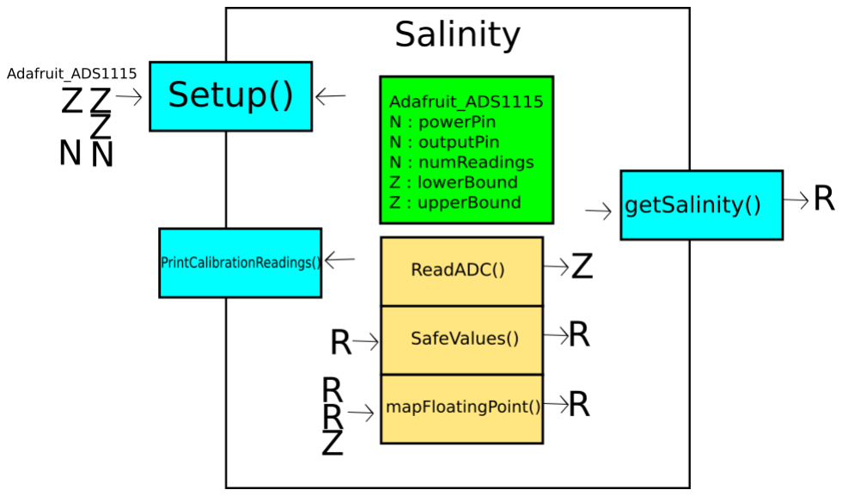
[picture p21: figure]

Ilustración 17. Diagrama UML del sensor de salinidad.

5.2 LIBRERÍAS

Como hemos mencionado, el proyecto depende de ciertas librerías. Algunas de ellas son internas; otras no. En el caso de las librerías de terceros, han sido instaladas desde el propio Arduino IDE, para la utilización de protocolos de comunicación o para interactuar con los sensores en cuestión. Véase debajo una lista de las librerías utilizadas.

INTERNAS
"GPS_A2235.h"
"REST_Server.h"
"System_Configuration.h"
"Sensors.h"
"Interruptions.h"
"SalinitySensor.h"
"HumiditySensor.h"
"TemperatureSensor.h"
"LuminositySensor.h"
"RainGauge.h"
"Arduino.h"
EXTERNAS
<Adafruit_ADS1015.h>
<Adafruit_BMP280.h>
<TinyGPS++.h>
<SoftwareSerial.h>
<Wire.h>
<ESP8266WiFi.h>
<Adafruit_Sensor.h>

5.3 PROGRAMA
Cabe mencionar nuevamente, que toda la base de código (clases, librerías, programas de prueba, etc.), esquemáticos y demás archivos esenciales pueden encontrarse en el repositorio git remoto del proyecto (enlace al repositorio). (https://github.com/abidanBrito/CDIO-SensorTech/tree/master/Sprint4/code/mainProgram)

Vol. 1

A continuación se adjunta el diseño de la configuración del sistema:

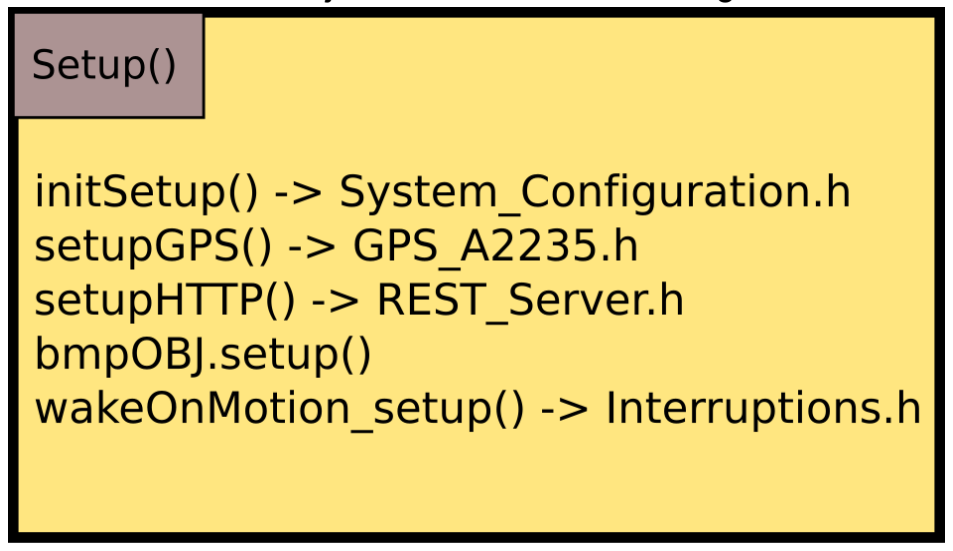
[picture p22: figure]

Ilustración 18. Diagrama de la configuración del programa

La función loop() se ejecuta indefinidamente durante el tiempo de ejecución del programa. En ésta acaece la creación de objetos (o instancias) de las mencionadas clases, la recopilación de datos de cada sensor, la geolocalización (si fuera posible), el envío de los datos a la API REST en orden sistemático y la hibernación (deepSleep) de la placa ESP8266. También se ejecuta el WOM, como medida de seguridad, bien sea por robo o movimientos sísmicos bruscos.

### 6 CONCLUSIONES Y LÍNEAS DE MEJORA

El objetivo primordial del proyecto es la recopilación de medidas de magnitudes físicas sensibles para el cultivo, permitiendo así su monitorización para optimizar y ajustar o adoptar técnicas en función a los datos recogidos. A día de hoy, se tiene una sonda agrícola capaz de realizar su función sin contratiempos y enviar los datos obtenidos a un servidor web, en el que se mantiene un registro global y representaciones gráficas de la humedad del subsuelo, la salinidad, la temperatura ambiental, la luminosidad, la presión barométrica, el volumen de precipitaciones y geolocalización.
También se han optimizado el consumo energético al máximo, optando por soluciones renovables, limpias y efectivas, así como usando la hibernación del microcontrolador y diseñando una PCB específica para esta primera versión del prototipo. Todo ello de acuerdo con la normativa medioambiental vigente.
Se puede mejorar el sistema de antirrobo, ya que las interrupciones del sistema deepSleep no son del todo precisas. También cabe mencionar que algunas de las implementaciones aquí expuestas son un poco arcaicas o simples, y por ende, tienen una tolerancia de error más grande de lo deseable en algunos casos.

Vol. 1

CONTROL DEL DOCUMENTO

Título: | Documento Técnico de Diseño
Volumen: | Vol. 2
Fecha: | 24 Enero 2020
Autor: | Abidán Brito Clavijo, Luis Belloch Martínez, Elvira Montagud Hernandis, Pablo Enguix Llopis
Referencia: | GTI_19_1A_TEAM_02
Nombre de fichero: Actas: | GTI_19_1A_TEAM_02
| Pueden ser consultadas en el repositorio remoto repositorio remoto. (https://github.com/abidanBrito/CDIO-SensorTech/blob/master/Sprint4/Actas_Daily_Scrum.pdf)

FIRMAS DEL DOCUMENTO

Naturaleza del firmante | Nombre | Firma | Fecha | Rol
Autores | Elvira Montagud Herrandis y Pablo Enguix Llopis | | 28/12/2019 | Miembro del equipo
Revisor | Abidán Brito Clavijo y Luis Belloch Martínez | | 13/01/2020 | Miembro del equipo

REGISTRO DE CAMBIOS DEL DOCUMENTO

Fecha | Versión | Autor | Detalles de los cambios
28/12/2019 | Vol 1. Borrador 1 | Elvira Montagud Hernandis, Pablo Enguix Llopis | Primer borrador.
7/1/2020 | Vol 1. Borrador 2 | Luis Belloch Martínez | Revisión y corrección.
23/01/2020 | Vol 1. Borrador 2 | Abidán Brito Clavijo | - Grado de protección IP. - Distribución eléctrica. - Responsabilidad ambiental y reciclaje.

Vol. 1

- Características del
sistema.
- Funcionalidades del
sensor BMP280.
- GPS.
- Corrección de
calibraciones.
- Definiciones y
acrónimos.
- Revisión general y
formato del documento.

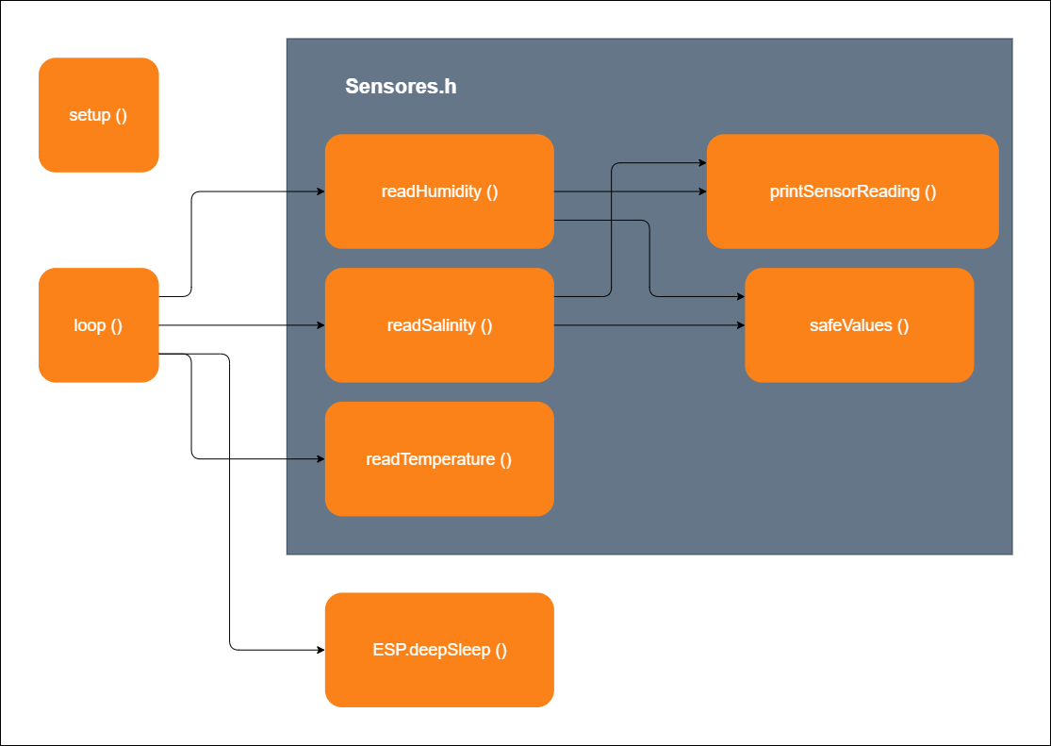
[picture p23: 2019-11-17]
img/software_architecture.png

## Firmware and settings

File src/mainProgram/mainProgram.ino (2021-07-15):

/*  ------------------------------------------------------------------------
    AUTHOR:        Abidan Brito Clavijo
    FILE:          mainProgram.ino
    DATE:          06/01/2020
    STATE:         DONE
    FUNCTIONALITY: This is the main file that is to be executed. It can be
    thought of as the center of the codebase.
    ------------------------------------------------------------------------
    NOTICE: (C) Copyright 2019. All rights reserved.
    ------------------------------------------------------------------------ */

//// IMPORT EXTERNAL LIBRARIES ////
#include "System_Configuration.h"  // System configuration.
#include "Sensors.h"               // Sensor-related miscellaneous.
#include "Interruptions.h"         // Wake on Motion & Deep Sleep.
#include "REST_Server.h"           // REST Server API.
#include "GPS_A2235.h"             // GPS receiver.

//----------------------------------------------------------------------
// Initial configuration.
//----------------------------------------------------------------------
void setup() {
    // Initial system configuration.
    init_setup();

    // GPS receiver configuration.
    setupGPS();

    // Pressure sensor configuration.
    bmp280_setup();

    // REST server configuration.
    setupHTTP();

    // Interruptions configuration.
    wakeOnMotion_setup();
}

//----------------------------------------------------------------------
// Runtime execution.
//----------------------------------------------------------------------
void loop() {
    // Salinity measure.
    double meanSalinity = salinityOBJ.getSalinity();

    // Humidity measure.
    double meanHumidity = humidityOBJ.getHumidity();

    // Temperature measure.
    double temperature_v1 = tempOBJ.getTemperature();

    // Light intensity measure.
    unsigned int lightState = lightOBJ.getLuminosityState();
    lightOBJ.printLightState();
    lightOBJ.printCalibrationReading();

    // Rainfall measure.
    double rainfall = rainOBJ.getRainfall();
    printSensorReading(rainfall, "Vase volume", "l");
    Serial.println();

    // Barometric pressure / Altitude measures.
    double barometricPressure = bmp280Pressure();
    double altitude = bmp280Altitude();
    double temperature_v2 = bmp280Temperature();
    bmp280_loop();

    // Send data over to the server.
    loopHTTP(meanSalinity, meanHumidity, temperature_v1,
             lightState, barometricPressure, altitude,
             rainfall);

    humidityOBJ.printCalibrationReading();

    // Geolocation (NMEA messages).
    loopGPS();

    // Hibernation mode.
    deepSleep_loop(HIBERNATION_TIME);
}

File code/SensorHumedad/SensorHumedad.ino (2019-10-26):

#include <Adafruit_ADS1015.h>

Adafruit_ADS1115 ads1115(0x48);

void setup() {

  Serial.begin(9600); // open serial port, set the baud rate as 9600 bps

  ads1115.begin();

  ads1115.setGain(GAIN_ONE);

}

void loop() {

  int val;

  val = ads1115.readADC_SingleEnded(0);

  Serial.println(val); //print the value to serial port

  delay(3000);
}

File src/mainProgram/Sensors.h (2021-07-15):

/*  ------------------------------------------------------------------------
    AUTHOR:         Abidan Brito Clavijo
    FILE:           Sensors.h
    DATE:           06/01/2020
    STATE:          DONE
    FUNCTIONALITY:  Miscellaneous library used by sensor objects.
    ------------------------------------------------------------------------
    NOTICE: (C) Copyright 2019 by Abidan Brito Clavijo. All rights reserved.
    ------------------------------------------------------------------------ */
#ifndef SENSORS_H
#define SENSORS_H

#include <Adafruit_Sensor.h>
#include <Adafruit_BMP280.h>

//// OBJECT DECLARATION ////
Adafruit_BMP280 bmp;    // Sensor object - I2C interface

//// MACRO DEFINITIONS ////
#define POWER_PIN_SALINITY      5
#define OUTPUT_PIN_SALINITY     0
#define OUTPUT_PIN_HUMIDITY     1
#define OUTPUT_PIN_TEMPERATURE  2
#define OUTPUT_PIN_LUMINOSITY   3
#define LOWER_BOUND_SALINITY    1150
#define LOWER_BOUND_HUMIDITY    20050
#define UPPER_BOUND_SALINITY    22000
#define UPPER_BOUND_HUMIDITY    10100
#define Y_INTERCEPT             0.786
#define SLOPE                   0.0348
#define D_TEMP                  -0.24
#define NUM_READINGS            5
#define ECHO_PIN_RAINGAUGE      0
#define TAZA_ASUN_ML            402.12

// ----------------------------------------------------------------------
// Print out the received data into the Serial Monitor.
// ----------------------------------------------------------------------
void printSensorReading(double measureValue, char* strLiteral, char* strUnit) {
    Serial.print(strLiteral);
    Serial.print(" = ");
    Serial.print(measureValue);
    Serial.print(" ");
    Serial.println(strUnit);
}

void bmp280_setup(void) {
    // Check communication with the sensor
    if (!bmp.begin()) {
        Serial.println("BMP280 sensor could not be found!");
        // Stop program flow with infinite loop
        while (1);
    }
    else {
        Serial.println("BMP280 sensor found!");
    }

    // Default settings from datasheet
    bmp.setSampling(Adafruit_BMP280::MODE_NORMAL,       // Operating Mode
                    Adafruit_BMP280::SAMPLING_X2,       // Temperature oversampling
                    Adafruit_BMP280::SAMPLING_X16,      // Pressure oversampling
                    Adafruit_BMP280::FILTER_X16,        // Filtering
                    Adafruit_BMP280::STANDBY_MS_500);   // Standby time
}

void bmp280_loop() {
    // Pressure
    float pressure = bmp.readPressure() / 100;
    Serial.print("Pressure\t=\t");
    Serial.print(pressure); // hPa (unit)
    Serial.println(" (hPa)");

    // Altitude
    Serial.print("Altitude\t=\t");
    Serial.print(bmp.readAltitude(pressure + 1));
    Serial.println(" (m)");

    // Temperature
    Serial.print("Temperature\t=\t");
    Serial.print(bmp.readTemperature());
    Serial.println(" (ºC)");

    // Line break to separate readings
    Serial.println();
}

double bmp280Pressure() {
    double pressure = bmp.readPressure() / 100;

    return pressure;
}

double bmp280Altitude() {
    double pressure = bmp.readPressure() / 100;
    double altitude = bmp.readAltitude(pressure + 1);

    return altitude;
}

double bmp280Temperature() {
    double temperature = bmp.readTemperature();

    return temperature;
}

#endif

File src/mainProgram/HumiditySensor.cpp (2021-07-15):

/*  ------------------------------------------------------------------------
    AUTHOR:         Abidan Brito Clavijo
    FILE:           HumiditySensor.cpp
    DATE:           02/01/2020
    STATE:          DONE
    FUNCTIONALITY:  Humidity sensor member functions (definitions).
    ------------------------------------------------------------------------
    NOTICE: (C) Copyright 2019 by Abidan Brito Clavijo. All rights reserved.
    ------------------------------------------------------------------------ */

#include "HumiditySensor.h"

//----------------------------------------------------------------------
// Salinity sensor constructor. It initializes all member variables.
//----------------------------------------------------------------------
HumiditySensor::HumiditySensor(Adafruit_ADS1115 * const adcAddress,
                               unsigned int const outputPin,
                               unsigned int const numReadings,
                               int16_t const lowerBound,
                               int16_t const upperBound)
    : adcAddress(adcAddress)
    , outputPin(outputPin)
    , numReadings(numReadings)
    , lowerBound(lowerBound)
    , upperBound(upperBound)
{}

//----------------------------------------------------------------------
// Several humidity readings. It returns the mean average (%).
//----------------------------------------------------------------------
double HumiditySensor::getHumidity() const {
    // Floating-point for precision (prevent overflow)
    double averageReading = 0.0;
    double percentageSum = 0.0;
    double const minPercentage = 0.0, maxPercentage = 100.0;

    for(unsigned int i = 0; i < this->numReadings; i++) {
        // Get new reading
        int16_t reading = this->readADC();

        // Convert reading to percentage and add it up
        percentageSum += mapFloatingPoint(reading, minPercentage, maxPercentage);
    }

    // Get mean average
    averageReading = percentageSum / this->numReadings;

    // Safety net (value within bounds)
    this->safeValues(&averageReading);

    return averageReading;
}

//----------------------------------------------------------------------
// Single ADC reading. It returns a signed integer (16-bit).
//----------------------------------------------------------------------
int16_t HumiditySensor::readADC() const {
    // Wait for sensor to settle
    delay(50);

    // Get reading
    int16_t reading = (*(this->adcAddress)).readADC_SingleEnded(this->outputPin);

    return reading;
}

//----------------------------------------------------------------------
// It makes sure the provided reading doesn't exceed percentage bounds.
//----------------------------------------------------------------------
double HumiditySensor::safeValues(double * const reading) const {
    double const maxPercentage = 100.0;
    double const minPercentage = 0.0;

    if(*reading > maxPercentage) {
        *reading = maxPercentage;
    }
    else if(*reading < minPercentage) {
        *reading = minPercentage;
    }
}

//----------------------------------------------------------------------
// Analogous to "map()", but this one uses floating-point arithmetic and
// old range parameters are known. It returns the mapped value.
//----------------------------------------------------------------------
double HumiditySensor::mapFloatingPoint(int16_t const adcReading,
                                        double const newLowerBound,
                                        double const newUpperBound) const {
    int16_t oldUpperBound = this->upperBound;
    int16_t oldLowerBound = this->lowerBound;
    int16_t oldRange = oldUpperBound - oldLowerBound;
    double newRange = newUpperBound - newLowerBound;

    return ((((adcReading - oldLowerBound) * newRange) / oldRange) + newLowerBound);
}

//----------------------------------------------------------------------
// It prints out the current voltage (V) into the Serial Monitor for
// calibration purposes.
//----------------------------------------------------------------------
void HumiditySensor::printCalibrationReading() const {
    Serial.print("Humidity = ");
    Serial.print(this->readADC());
    Serial.println(" (ADC reading)");
}

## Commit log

2019-10-26 Humidity sensor program - v1.0
    The program works; it has been calibratred and tested. It might, however, need some revisions down the line. Right now, it takes a while for the values to change when changing state (medium). It sett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
2019-10-26 Salinity sensor - Electronic schematic
    Sprint 1 started. Added electronic schematic (Fritzing). It uses the Sparkfun ESP8266 and the ADS1115 ADC.
    [SensorSalinidad.fzz]
2019-10-26 Moved file to correct location within repository.
    [SensorHumedad.ino]
2019-10-26 Proper root directory added (for Arduino IDE).
2019-10-26 Humidity sensor program - v1.0
    At its current state, the program works. It has been tested and calibrated (bounds). However, calibration is a little off, due to some changes in the design of the schematic. It needs further testing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
2019-10-26 Salinity sensor program - v1.0
    The program has been calibrated and tested. There might be further evaluation involved, but so far it seems to work.
2019-10-26 Salinity & Humidity Integration program - v1.0
    Simple template for integration of the other two working versions. At this stage, it may contain errors.
2019-10-26 Salinity & Humidity Integration program - v2.0
    Program integration complete. New header, comments and more structured coding standards. We need to run a few more tests, as we may have to change some macros (calibration bounds).
2019-10-26 Salinity & Humidity Integration Program - v2.1
    Each sensor has its own power pin and the measure calculations are more precise now.
2019-10-26 Humidity sensor - Electronic schematic
2019-10-26 Architectures about the program and the device
2019-10-26 Updated deviceArchitecture.png
2019-10-26 Salinity sensor schematic
2019-10-26 Added labels for electronic components
    [SensorHumedad.fzz, SensorSalinidad.fzz]
2019-10-26 Humidity sensor schematic
2019-10-28 New sensor calibrated
2019-10-29 Temperatura v0.1
    Primera versión del sensor de temperatura
2019-10-29 SensorTemperatura v0.1
    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
2019-11-03 Fixed a couple things
2019-11-12 Added temperature scheme
    [SensorTemperatura.fzz]
2019-11-12 Added accelerometer scheme (WIP)
    [Acelerómetro.fzz]
2019-11-12 Removed ADC library (double declaration)
2019-11-12 Updated Accelerometer scheme
    [Acelerómetro.fzz]
2019-11-14 Wrong directory name
    [SensorSalinidad.fzz]
2019-11-14 Reuploaded schematics
    [SensorHumedad.fzz, SensorSalinidad.fzz]
2019-11-14 WIP schematics
    [Acelerómetro.fzz, SensorTemperatura.fzz]
2019-11-16 Esquema Deep Sleep
    Esquema en .Fzz para la documentación de la función Deep Sleep
    [DeepSleep.fzz]
2019-11-16 Temperatura en main
    Añadida la función de temperatura a sensores.h y su acceso desde mainProgram.ino
2019-11-16 Esquema sensores.h
2019-11-17 Añadido Burndown
    Finalizadas las actividades y añadido el diagrama de burndown
2019-11-19 Changed position of the accelerometer schematic
    [Acelerómetro.fzz]
2019-11-19 Diseño esquemático fotosensor
    [SensorLuz.fzz]
2019-11-26 Fixed electronic schematics
    [DeepSleep.fzz, SensorHumedad.fzz, SensorLuz.fzz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]
2019-11-26 Added GPS receiver electronic schematic
2019-11-27 Change accelerometer model
    [Acelerómetro.fzz]
2019-11-30 Fixed schematics
    [Accelerometer_DeepSleep.fzz, SensorLuz.fzz]
2019-12-07 Esquema del pluviómetro
    El sensor es el HC-SR04
    [Pluviómetro.fzz]
2019-12-09 Barometric pressure and altitude
2019-12-09 Updated schematics
    [SensorSalinidad.fzz, SensorTemperatura.fzz]
2019-12-09 Temperature calibrated
2019-12-10 Wake-on Motion
    Funciona por sí mismo pero falla con el deep-sleep
2019-12-10 Boceto de la PCB
    [Proyecto_GTI_1A_1cara_2019_Template.fzz]
2019-12-10 Initial codebase (with interruptions)
2019-12-10 Wrong location
    [prototipo placa PCB.fzz]
2019-12-10 PCB design - v1
    [PCB_design_v1.fzz]
2019-12-10 Fixed a bunch of issues
    [GPS_A2235.h, Sensors.h, mainProgram.ino]
2019-12-10 Fixed minor comment issue
    [mainProgram.ino]
2019-12-11 Added ultrasonic sensor in use
2019-12-11 Fritzing de la Placa PCB
    Pendiente de revisión ¡No entregar todavía!
    [Placa_PCB.fzz]
2019-12-11 Incomplete file (no longer needed)
    [Proyecto_GTI_1A_1cara_2019_Template.fzz]
2019-12-11 PCB v1.0
    [PCB_v2.fzz]
2019-12-16 Added pluviometer+salinity schematic
    [Pluviómetro+Salinidad.fzz]
2019-12-25 Final version
    [PCB_v3.fzz]
2019-12-25 Salinity and Rain Gauge Integration
    [Salinity_and_Rain_Gauge.fzz]
2019-12-25 Messy wire layout
    [Pluviómetro+Salinidad.fzz]
2019-12-28 Fixed temperature schematic
    [SensorTemperatura.fzz]
2019-12-28 Fixed salinity schematic
    [SensorSalinidad.fzz]
2019-12-28 Fixed and labeled schematics
    [Accelerometer_DeepSleep.fzz, Acelerómetro.fzz, DeepSleep.fzz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]
2019-12-28 Old file
    [Salinity_and_Rain_Gauge.fzz]
2019-12-28 Final schematics
    [DeepSleep.fzz, Light_Intensity.fzz, Rain_Gauge.fzz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]
2019-12-28 Class versions of each sensor
2019-12-28 Objects corrected for each sensor
    Validation required
2020-01-02 Added salinity and temperature sensor classes
2020-01-02 Added humidity sensor and fixed others
    [HumiditySensor.cpp, TemperatureSensor.cpp]
2020-01-02 Added luminosity sensor and fixed some issues
    [LuminositySensor.cpp, SalinitySensor.cpp]
2020-01-02 Sensor de presión barométrica BMP280
    Su esquema completo
    [BMP280.fzz]
2020-01-02 Fixed a bunch of issuesç
    [HumiditySensor.cpp, LuminositySensor.cpp, SalinitySensor.cpp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]
2020-01-03 Added global schematic and improved the GPS schematic
    [GPS_Receiver.fzz, Scheme.fzz]
2020-01-06 Update sensor classes
2020-01-06 Fixed some conflicting issues
    [BMP280.cpp, LuminositySensor.cpp, REST_Server.h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]
2021-07-15 removed all wip files from old sprints
    [DeepSleep.fzz, Light_Intensity.fzz, PCB_v2.fzz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]
